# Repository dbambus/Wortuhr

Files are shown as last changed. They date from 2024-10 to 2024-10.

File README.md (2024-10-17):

  
# ESP Wordclock

English description further below.



Dies ist ein Projekt für eine mehrsprachige Wortuhr auf Grundlage eines ESP8266-Mikrocontrollers und einer programmierbaren LED-Leiste (WS2812 oder SK6812). Eine Wortuhr ist ein wunderschönes DIY-Projekt für Anfänger, das Technologie und Design kombiniert, um eine funktionale und ästhetisch ansprechende Uhr zu schaffen. 
Egal, ob Sie ein Anfänger oder ein erfahrener Bastler sind, dieses Projekt ist eine großartige Möglichkeit, Ihre Fähigkeiten unter Beweis zu stellen und etwas wirklich Besonderes zu schaffen.
Die Software hat viele Funktionen:
- Mehrsprachig (🇬🇧, 🇩🇪, 🇪🇸, 🇮🇹, 🇳🇱, 🇭🇺, 🇷🇴, 🇨🇭, 🇷🇺, 🇸🇪, 🇫🇷)
- Unterstützung für mehrere Layouts und LED-Abstände
- Farbwechsel der Displayfarbe möglich (RGB oder RGBW)
- Digitale Uhranzeige
- Regenbogenfarbwechsel
- Umgebungslicht (als Sekundenzeiger ausgeführt) 
- Automatische Helligkeitsregelung (optional über LDR) 
- Auswahl an dialektspezifischen Anzeigen
- Home-Assistant-Einbindung mit Autodiscovery



## Betriebsmodi der Uhr

<p align="center">
Wordclock DigitalClock
Colors Rainbow
Symbol Seconds
ScrollingText Animation
FrameSeconds 
</p>

## Die folgende Hardware/Software wird für dieses Projekt benötigt:
* Hardware
    * NodeMCU oder vergleichbares Board mit einem dem ESP8266 oder ESP8285 Chip
    * WS2812B RGB-LED-Streifen oder SK6812 RGBW-Streifen
    * Stromversorgung 5V 2A
    * Optional: LDR, 10 KOhm-Widerstand

* Software
    * PlatformIO [Core](https://docs.platformio.org/en/latest/core/installation.html) oder [IDE](https://platformio.org/install/ide?install=vscode)
    * [Node.js](https://www.nodejs.org/)
    * [Git](https://git-scm.com)

## Installation 
### Windows

* Installieren Sie PlatformIO IDE, Node.js und Git manuell über die oben genannten Links.
* Dadurch wird Visual Studio Code installiert, mit einem PlatformIO-Symbol (Ameisenkopf/Alien) in der Seitenleiste.
* Gehen Sie zu 'Quick Access / Miscellaneous' und geben Sie den Befehl 'Clone Git Project' ein, und geben Sie 'https://github.com/ESPWortuhr/Wortuhr' als URL ein.
* Gehen Sie dann zu 'Projekte', fügen Sie das neue Projekt mit 'Vorhandenes hinzufügen' zur Liste hinzu und klicken Sie auf 'Öffnen'.
* In der PlatformIO-Seitenleiste erscheint nun 'Project Tasks'. Wählen Sie den Befehl 'General / Upload' (dauert ein paar Minuten, die Software wird zuerst erstellt).
* Schließen Sie den ESP-8266 über USB an. Wenn die Wortuhr-Software erstellt ist, wird sie auf dem ESP installiert.

### MacOS

Der einfachste Weg wäre mit [homebrew](https://docs.brew.sh/Installation):

```sh
brew install platformio
brew install node
git clone https://github.com/ESPWortuhr/Wortuhr
cd Wortuhr
pio run -t upload
```

### Linux

```sh
python3 -c "$(curl -fsSL https://raw.githubusercontent.com/platformio/platformio/master/scripts/get-platformio.py)"
sudo apt install npm
git clone https://github.com/ESPWortuhr/Wortuhr
cd Wortuhr
pio run -t upload
```

## Anschließen des WS2812/ SK6812 LED Streifens
* RX = DI / Datenbus
* G = GND / Masse
* VU = 5V

## Anschluss der Hardware
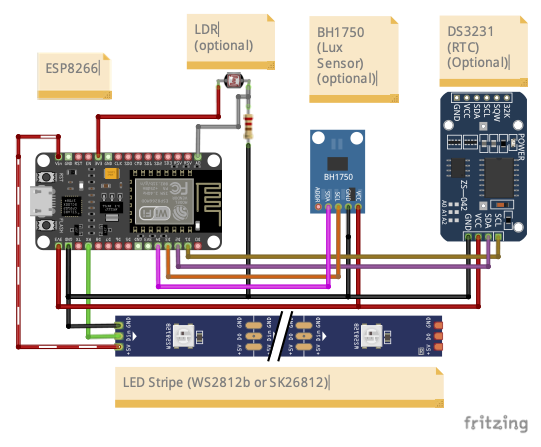
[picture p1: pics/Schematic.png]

      
## Verzeichnisstruktur

- `pics` enthält Bilder
- `svg` enthält SVG-Dateien
- `include` enthält C-Header-Dateien
- `src` enthält C-Quelldateien
- `webpage` enthält das Webinterface
- `docs` enthält Handbücher
- `templates` enthält Fräs- und Laserdaten

### BSD-3 Lizenz

Diese Software ist unter der BSD-Lizenz lizenziert und darf frei verwendet werden. Es ist erlaubt, sie zu kopieren, zu verändern und zu verbreiten.
Die einzige Bedingung ist, dass der Copyright-Hinweis des Originalprogramms nicht entfernt werden darf.

## ENGLISH Textversion



This is a project for a multilingual word clock based on an ESP8266 microcontroller and a programmable LED strip (WS2812 or SK6812). A word clock is a beautiful DIY project for beginners that combines technology and design to create a functional and aesthetically pleasing clock. 
Whether you're a beginner or an experienced hobbyist, this project is a great way to show off your skills and create something truly special.
The software has many features:
- Multilingual  (🇬🇧, 🇩🇪, 🇪🇸, 🇮🇹, 🇳🇱, 🇭🇺, 🇷🇴, 🇨🇭, 🇷🇺, 🇸🇪, 🇫🇷)
- Support for multiple layouts and LED spacing
- Colour change of the display colour possible (RGB or RGBW)
- Digital clock display
- Rainbow colour change
- Ambient light (designed as a second hand) 
- Automatic brightness control (optional via LDR) 
- Selection of dialect-specific displays
- Home Assistant integration with auto-discovery
  


## The following hardware/software are required for this project:
* Hardware
    * NodeMCU (tested board Lolin Version3 and Wemos D3 mini) or comparable board with an ESP8266 
    * WS2812B, WS2816 RGB LED Stripes or SK6812 RGBW Stribes
    * Power supply 5V 2A
    * Optional: LDR, 10 KOhm resistor
* Software
    * PlatformIO [Core](https://docs.platformio.org/en/latest/core/installation.html) or [IDE](https://platformio.org/install/ide?install=vscode)
    * [Node.js](https://www.nodejs.org/)
    * [Git](https://git-scm.com)

## Installation 
### Windows

* Manually install PlatformIO IDE, Node.js and Git using the links above.
* This will install Visual Studio Code, with a PlatformIO icon (ant head/alien) in the sidebar.
* Go to 'Quick Access / Miscellaneous' and enter the command 'Clone Git Project', and enter 'https://github.com/ESPWortuhr/Wortuhr' as the URL.
* Then go to 'Projects', add the new project to the list by 'Add Existing' and click on 'Open'.
* Then in the PlatformIO sidebar 'Project Tasks' appears. Select the command 'General / Upload' (takes a few minutes, the software will be built first).
* Connect the ESP-8266 via USB. When the word clock software is built, it will be installed on the ESP.

### MacOS

The easiest way would be with [homebrew](https://docs.brew.sh/Installation):

```sh
brew install platformio
brew install node
git clone https://github.com/ESPWortuhr/Wortuhr
cd Wortuhr
pio run -t upload
```

### Linux

```sh
python3 -c "$(curl -fsSL https://raw.githubusercontent.com/platformio/platformio/master/scripts/get-platformio.py)"
sudo apt install npm
git clone https://github.com/ESPWortuhr/Wortuhr
cd Wortuhr
pio run -t upload
```

## Connecting the WS2812/ SK6812 Stripe
* RX = DI / Data Bus
* G = GND / Masse
* VU = 5V

## Connection of the hardware

      
## directory structure

- `pics` contains images
- `svg` contains SVG files
- `include` contains C header files
- `src` contains C source files
- `webpage` contains the web interface
- `docs` contains manuals
- `templates` contains milling and laser data

## To DO & (Ideen):
* HomeKit Support
* Home Assistant Support

### BSD-3 License

This software is licensed under the BSD license and may be used freely. It is allowed to copy, modify and distribute it.
The only condition is that the copyright notice of the original program must not be removed.

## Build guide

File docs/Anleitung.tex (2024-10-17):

\documentclass[12pt,a4paper, german,oneside, headinclude, headsepline,plainheadsepline,BCOR20mm, DIV18,parskip=half, openright, numbers=noenddot, captions=tableheading,version=first,listof=totoc,version=first]{scrbook}

\hfuzz=20pt
\vfuzz=20pt

%--------------- Packages ----------------
\usepackage[ngerman]{babel}
\usepackage[utf8]{inputenc}
\usepackage[T1]{fontenc}
\usepackage{lmodern}
\usepackage[centertags]{amsmath} 
\usepackage{tabularx}
\usepackage{graphicx} 
\usepackage{float} 
\usepackage{setspace} 
\usepackage{scrlayer-scrpage}
\usepackage{scrhack}
\usepackage{makeidx}
\usepackage[usenames,dvipsnames,svgnames,table]{xcolor}
\usepackage[absolute]{textpos}
\usepackage{subfigure}
\usepackage{amssymb}
\usepackage{listings}
\usepackage{trfsigns}
\usepackage{siunitx}
\usepackage[abs]{overpic}
\usepackage[colorlinks = false,pdfpagelabels = true,pdfstartview = FitH,bookmarksopen = true,bookmarksnumbered = true,linkcolor = black,plainpages = false,hypertexnames = false,citecolor = black] {hyperref}
\usepackage{pgfplots}
\usepackage[framed,numbered,autolinebreaks,useliterate]{mcode}
\usepackage{xcolor}
\usepackage[
    left = \flqq{},% 
    right = \frqq{},% 
    leftsub = \flq{},% 
    rightsub = \frq{} %
]{dirtytalk}
\lstset{breaklines=true}

\pagestyle{scrheadings}
\renewcommand{\headfont}{\normalfont\sffamily} 
\renewcommand{\pnumfont}{\normalfont\sffamily} 
\ohead[\pagemark]{\pagemark} 
\ifoot[]{}
\ofoot[]{}
\setlength{\headheight}{1.5\baselineskip}
\onehalfspacing

%----------------------- Beginn des Dokuments -----------------------
\begin{document}
\pagenumbering{Roman}
\thispagestyle{empty}
\setcounter{page}{-1}



\vspace{25mm}

{\centering

\LARGE\textbf{{Anleitung}}\\
\vspace{1em}
\large{Für die Multilayout-ESP-Wordclock} \\

\par}

\newpage
\thispagestyle{empty}

\cleardoublepage

\cleardoublestandardpage

\begin{spacing}{1.15}		
\pdfbookmark[1]{Inhaltsverzeichnis}{toc}		
\tableofcontents 		

\end{spacing}

\cleardoublestandardpage

\mainmatter							

\chapter{Einleitung}

Diese Anleitung soll helfen, eine mehrsprachige Wortuhr zu bauen, die auf einem ESP8266 Mikrocontroller und einer programmierbaren LED-Leiste (WS2812 oder SK6812) basiert. Dieses Projekt wurde über mehrere Jahre von einer Vielzahl von Mitwirkenden auf Github entwickelt und frei zur Verfügung gestellt.\\
Eine Wortuhr (auch als Wordclock bekannt) ist ein schönes DIY-Projekt für Anfänger, das Technologie und Design kombiniert, um eine funktionelle und ästhetisch ansprechende Uhr zu schaffen. Egal, ob Sie Anfänger oder erfahrener Bastler sind, dieses Projekt ist eine großartige Gelegenheit, Ihre Fähigkeiten unter Beweis zu stellen und etwas wirklich Besonderes zu schaffen. Die Gestaltungsmöglichkeiten liegen vor allem im Rahmen und in der Wahl der Oberfläche der Uhr. 

\section{Hauptfunktionen}

Die bereitgestellte Software zum Betreiben der Wortuhr hat mehrere Funktionen:

\begin{itemize}
    \item Mehrsprachig (Deutsch, Englisch, Niederländisch, Italienisch, Spanisch, Ungarisch, Französisch, Römänisch, Schweizer Deutsch, Russisch und Schwedisch)
    \item Unterstützung für mehrere Matrizengrößen und LED-Abstände
    \item Farbwechsel der Anzeigefarbe möglich (RGB oder RGBW)
    \item Digitale Uhranzeige
    \item Regenbogenfarbwechsel
    \item Umgebungslicht (als Sekundenzeiger ausgeführt oder Ambientlight)
    \item Automatische Helligkeitsregelung (optional über Sensor)
    \item Offlinebetrieb (optional über entsprechende RTC)
    \item Auswahl an dialektspezifischen Anzeigen
    \item Home-Assistant-Einbindung mit Autodiscovery
\end{itemize}

\section{Uhren Varianten}

\section{Voraussetzungen}

Die folgende Hardware/Software wird für dieses Projekt benötigt:

\subsubsection{Hardware}

\begin{itemize}
    \item NodeMCU oder vergleichbares Board mit einem dem ESP8266 oder ESP8285 Chip
    \item WS2812B RGB-LED-Streifen oder SK6812 RGBW-Streifen
    \item Stromversorgung 5V 2A
    \item Optional: LDR, 10 KOhm-Widerstand
    \item Optional: BH1750 (digitaler Helligkeitssensor, anstallt LDR)
    \item Optional: DS3231 (Echtzeituhr, für den offline Betrieb)
\end{itemize}

\subsubsection{Software}

\begin{itemize}
    \item PlatformIO Core oder IDE (bspw. VIsual Studio Code)
    \item Node.js
    \item Git
\end{itemize}

\chapter{Installation der Wortuhr Software}

\section{Erstmaliges Aufspielen mittels Binary}
Für das erstmalige Aufspielen liegen auf der Githubseite Rechts \say{Releases} zur Verfügung. Dabei handelt es sich um fertig compilierte Versionen der Software. Programme zum aufspielen der binary findet man z.B. unter \say{https://github.com/nodemcu/nodemcu-flasher}

\section{Windows}

\begin{enumerate}
    \item Installieren Sie die aktellsten Versionen von PlatformIO, Node.js und Git manuell
    \item Dadurch wird Visual Studio Code installiert, mit einem PlatformIO-Symbol (Ameisenkopf/Alien) in der Seitenleiste
    \item Gehen Sie zu \say{Quick Access / Miscellaneous} und geben Sie den Befehl \say{Clone Git Project} ein, und geben Sie \href{https://github.com/ESPWortuhr/Multilayout-ESP-Wordclock}{https://github.com/ESPWortuhr/Multilayout-ESP-Wordclock} als URL ein
    \item Gehen Sie dann zu \say{Projekte}, fügen Sie das neue Projekt mit \say{Vorhandenes hinzufügen} zur Liste hinzu und klicken Sie auf \say{Öffnen}.
    \item In der PlatformIO-Seitenleiste erscheint nun \say{Project Tasks}. Wählen Sie den Befehl \say{General / Upload'} (dauert ein paar Minuten, die Software wird zuerst erstellt).
    \item Schließen Sie den ESP8266 über USB an. Wenn die Wortuhr-Software erstellt ist, wird sie auf dem ESP installiert.
\end{enumerate}

\section{MacOS}

Der einfachste Weg wäre mit \say{homebrew}:

\begin{lstlisting}
    brew install platformio
    brew install node
    git clone https://github.com/ESPWortuhr/Wortuhr
    cd Wortuhr
    pio run -t upload
\end{lstlisting}

Dabei ist der ESP8266 über USB angeschlossen. Die Wortuhr-Software wird dabei mittels Plattformio erstellt und auf den ESP übertragen.

\section{Linux}

\begin{lstlisting}
    python3 -c "$(curl -fsSL https://raw.githubusercontent.com/ platformio/platformio/master/scripts/get-platformio.py)"
    sudo apt install npm
    git clone https://github.com/ESPWortuhr/Wortuhr
    cd Wortuhr
    pio run -t upload
\end{lstlisting}

Dabei ist der ESP8266 über USB angeschlossen. Die Wortuhr-Software wird dabei mittels Plattformio erstellt und auf den ESP übertragen.

\section{Update der Firmware über das Web-Frontend}
Mit der Software ist es möglich, die Firmware \textbf{OTA} (over the air), über den in der Uhr eingebauten Webserver zu aktualisieren. Dies ist in den meisten Fällen einfacher als das direkte Flashen.
Ausschlaggebend für diese Vorgehensweise ist, dass die Uhr über WLAN erreichbar ist. Die Update-Schnittstelle ist dann über die Adresse
http://<IP-Adresse der Uhr>:81/update erreichbar (Beispiel: http://192.168.4.1:81/update). Die Adresse der Uhr wird in der Grundeinstellung beim Start als Laufschrift ausgegeben.

\chapter{Hardware}

Für den Aufbau der Wortuhr wird folgende elektronische Hardware benötigt:

\begin{itemize}
    \item NodeMCU oder vergleichbares Board mit ESP8266 oder ESP8285 Chip
    \item RGB-LED-Streifen WS2812B oder RGBW-Streifen SK6812
    \item Stromversorgung 5V 2A
    \item Optional: LDR, 10 KOhm Widerstand
    \item Optional: BH1750 (digitaler Helligkeitssensor, ersetzt LDR)
    \item Optional: DS3231 (Echtzeituhr, für Offline-Betrieb)
\end{itemize}

Ich möchte dich gerne darüber informieren, was du noch alles für den Bau benötigst. Da es verschiedene Arten gibt, eine Uhr zu bauen, werde ich dir hier nur die grundlegenden Dinge aufzählen, die ich oft verwende:

\begin{itemize}
    \item Bilderrahmen (Holz oder Metall mit mindestens 14mm Rahmenhöhe)
    \item Diffusorfolie
    \item Buchstabenmaske
    \item Abstandsgitter (Holz oder Kunststoffschaum)
\end{itemize}

\section{Pegelanpassung}

Der ESP arbeitet intern mit einer Betriebsspannung von 3,3V. Die WS2812(B) Streifen arbeiten dagegen mit 5V. Dies erfordert eine Pegelanpassung, damit die digitalen Signale fehlerfrei zu den Stripes übertragen warden können. Ohne Anpassung kann es auch funktionieren, muss es aber nicht. 
Es gilt: "Der minimale High-Pegel des Ausgangs muss höher sein als der minimale High-Pegel des Eingangs"
Was heißt das im Klartext?
Laut Datenblatt des Stripes sind folgende Pegel notwendig, um ein "sauberes" HIGH und LOW Signal zu bekommen.
Um ein HIGH Signal am Eingang des WS2812B Stripes zu erzeugen, muss laut Datenblatt (Bild 1) mindestens ein Pegel von 4,3V erzeugt werden. Da der ESP aber maximal 3,3V erzeugen kann, wird hier kein sicheres HIGH Signal erzeugt.

Nun kommt der Trick mit der Diode:
Die erste LED wird nun mit einer Diode in der Plus Leitung betrieben. Die Durchlassspannung der Diode beträgt 0,7V. Das heißt, dass die erste Diode mit 4,3V betrieben wird. Das ist laut Datenblatt auch zulässig. Bei 4,3V beträgt der benötigte HIGH Pegel nun noch 3,6V. Da die Hersteller noch Toleranzen mit einberechnen funktioniert das ganze Konstrukt wieder. Nun gibt die erste LED den Pegel mit 4,3V an die nächste LED weiter (diese wird wieder mit 5V betrieben und der HIGH Pegel liegt mit 4,3V wieder im Datenblatt in der Toleranz). Die zweite LED verstärkt sozusagen das Signal wieder auf die volle 5V.
Das heißt, die erste LED wird sozusagen als Pegelanpassung missbraucht.

\section{Anschlussbeispiel}
Der Datenpin des LED Stripes muss zwingend an dem Port \say{Rx} angeschlossen werden. Grund für den festen Pin ist die verwendete Library. Der Pin kann nicht verändert werden (auch nicht in der Config). Wie auf dem muss eine Diode in die +5V Leitung der 1. LED. Die +5V Leitung zwischen der 1. und 2. LED muss durchtrennt werden (aber nur diese, nicht die Daten und GND!).
Am 2. Streifen wird dann zusätzlich vom Netzteil die +5V eingespeist. Die LED´s vom 1. Stripe werden dann sozusagen "rückwärts" mit den nötigen +5V versorgt.

    \begin{figure} [h]
		\centering
		 
		\caption{Anschlussbeispiel}
		\label{abb.Schematic}
	\end{figure}

\chapter{Funktionen der Uhrensoftware auf dem ESP}

\section{Verbinden der Uhr mit dem eigenen WLAN}
Nach dem erfolgreichen Verbinden kann die Uhr nach Eingabe der angezeigten IP-Adresse in einem Browser konfiguriert werden. Dabei kann die Uhr auch mit dem eigenen WLAN Netz verbunden werden.
 
\section{Zeitserver (NTP Server)}
Falls die Uhr an das eigene WLAN mit Internet angebunden wird, kann ein Zeitserver hinterlegt werden. Dieser sorgt dafür, dass die Uhrzeit zyklisch sekundengenau gestellt wird. 
 
\section{Automatische Helligkeitsregelung}
Falls der optionale LDR an der Uhr angeschlossen wurde, ist es möglich, die Helligkeit automatisch, abhängig der Umgebungshelligkeit, regeln zu lassen. Dazu muss folgende Einstellung aktiviert werden. Durch das Feld Kalibrierung kann man die Grundhelligkeit an seine eigenen Wünsche anpassen.

\end{document}

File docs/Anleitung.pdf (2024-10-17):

!!

M | E | S | P | I | W | O | R | D | F
B | A | C | L | O | C | K | D | A | N
E | A | N | A | L | L | E | E | F | T
M | A | N | U | A | L | N | J | L | K

# Anleitung

Für die Multilayout-ESP-Wordclock

# Inhaltsverzeichnis

1 Einleitung | 1
2 Installation der Wortuhr Software | 3
3 Hardware | 5
4 Funktionen der Uhrensoftware auf dem ESP | 8

# 1 Einleitung

Diese Anleitung soll helfen, eine mehrsprachige Wortuhr zu bauen, die auf einem ESP8266 Mikrocontroller und einer programmierbaren LED-Leiste (WS2812 oder SK6812) basiert. Dieses Projekt wurde über mehrere Jahre von einer Vielzahl von Mitwirkenden auf Github entwickelt und frei zur Verfügung gestellt.
Eine Wortuhr (auch als Wordclock bekannt) ist ein schönes DIY-Projekt für Anfänger, das Technologie und Design kombiniert, um eine funktionelle und ästhetisch ansprechende Uhr zu schaffen. Egal, ob Sie Anfänger oder erfahrener Bastler sind, dieses Projekt ist eine großartige Gelegenheit, Ihre Fähigkeiten unter Beweis zu stellen und etwas wirklich Besonderes zu schaffen. Die Gestaltungsmöglichkeiten liegen vor allem im Rahmen und in der Wahl der Oberfläche der Uhr.

## 1.1 Hauptfunktionen

Die bereitgestellte Software zum Betreiben der Wortuhr hat mehrere Funktionen:

- Mehrsprachig (Deutsch, Englisch, Niederländisch, Italienisch, Spanisch, Ungarisch, Französisch, Römänisch, Schweizer Deutsch, Russisch und Schwedisch)
- Unterstützung für mehrere Matrizengrößen und LED-Abstände
- Farbwechsel der Anzeigefarbe möglich (RGB oder RGBW)
- Digitale Uhranzeige
- Regenbogenfarbwechsel
- Umgebungslicht (als Sekundenzeiger ausgeführt oder Ambientlight)
- Automatische Helligkeitsregelung (optional über Sensor)
- Offlinebetrieb (optional über entsprechende RTC)

1 Einleitung | 2
- Auswahl an dialektspezifischen Anzeigen
- Home-Assistant-Einbindung mit Autodiscovery

## 1.2 Uhren Varianten

## 1.3 Voraussetzungen

Die folgende Hardware/Software wird für dieses Projekt benötigt:

Hardware

- NodeMCU oder vergleichbares Board mit einem dem ESP8266 oder ESP8285 Chip
- WS2812B RGB-LED-Streifen oder SK6812 RGBW-Streifen
- Stromversorgung 5V 2A
- Optional: LDR, 10 KOhm-Widerstand
- Optional: BH1750 (digitaler Helligkeitssensor, anstallt LDR)
- Optional: DS3231 (Echtzeituhr, für den offline Betrieb)

Software

- PlatformIO Core oder IDE (bspw. VIsual Studio Code)
- Node.js
- Git

# 2 Installation der Wortuhr Software

## 2.1 Erstmaliges Aufspielen mittels Binary

Für das erstmalige Aufspielen liegen auf der Githubseite Rechts «Releases» zur Verfügung. Dabei handelt es sich um fertig compilierte Versionen der Software. Programme zum aufspielen der binary findet man z.B. unter «https://github.com/nodemcu/nodemcuflasher»

## 2.2 Windows

1. Installieren Sie die aktellsten Versionen von PlatformIO, Node.js und Git manuell
2. Dadurch wird Visual Studio Code installiert, mit einem PlatformIO-Symbol (Ameisenkopf/Alien) in der Seitenleiste
3. Gehen Sie zu «Quick Access / Miscellaneous» und geben Sie den Befehl «Clone Git Project» ein, und geben Sie https://github.com/ESPWortuhr/Multilayout-ESP-Wordclock als URL ein
4. Gehen Sie dann zu «Projekte», fügen Sie das neue Projekt mit «Vorhandenes hinzufügen» zur Liste hinzu und klicken Sie auf «Öffnen».
5. In der PlatformIO-Seitenleiste erscheint nun «Project Tasks». Wählen Sie den Befehl «General / Upload’» (dauert ein paar Minuten, die Software wird zuerst erstellt).
6. Schließen Sie den ESP8266 über USB an. Wenn die Wortuhr-Software erstellt ist, wird sie auf dem ESP installiert.

2 Installation der Wortuhr Software | 4

## 2.3 MacOS

Der einfachste Weg wäre mit «homebrew»:

1 | brew install platformio
2 | brew install node
3 | git clone https://github.com/ESPWortuhr/Wortuhr
4 | cd Wortuhr
5 | pio run -t upload

Dabei ist der ESP8266 über USB angeschlossen. Die Wortuhr-Software wird dabei mittels Plattformio erstellt und auf den ESP übertragen.

## 2.4 Linux

1 | python3 -c "$(curl -fsSL https://raw.githubusercontent.com/ ...
| platformio/platformio/master/scripts/get-platformio.py)"
2 | sudo apt install npm
3 | git clone https://github.com/ESPWortuhr/Wortuhr
4 | cd Wortuhr
5 | pio run -t upload

Dabei ist der ESP8266 über USB angeschlossen. Die Wortuhr-Software wird dabei mittels Plattformio erstellt und auf den ESP übertragen.

## 2.5 Update der Firmware über das Web-Frontend

Mit der Software ist es möglich, die Firmware OTA (over the air), über den in der Uhr eingebauten Webserver zu aktualisieren. Dies ist in den meisten Fällen einfacher als das direkte Flashen. Ausschlaggebend für diese Vorgehensweise ist, dass die Uhr über WLAN erreichbar ist. Die Update-Schnittstelle ist dann über die Adresse http://<IP-Adresse der Uhr>:81/update erreichbar (Beispiel: http://192.168.4.1:81/update). Die Adresse der Uhr wird in der Grundeinstellung beim Start als Laufschrift ausgegeben.

# 3 Hardware

Für den Aufbau der Wortuhr wird folgende elektronische Hardware benötigt:

- NodeMCU oder vergleichbares Board mit ESP8266 oder ESP8285 Chip
- RGB-LED-Streifen WS2812B oder RGBW-Streifen SK6812
- Stromversorgung 5V 2A
- Optional: LDR, 10 KOhm Widerstand
- Optional: BH1750 (digitaler Helligkeitssensor, ersetzt LDR)
- Optional: DS3231 (Echtzeituhr, für Offline-Betrieb)

Ich möchte dich gerne darüber informieren, was du noch alles für den Bau benötigst. Da es verschiedene Arten gibt, eine Uhr zu bauen, werde ich dir hier nur die grundlegenden Dinge aufzählen, die ich oft verwende:

- Bilderrahmen (Holz oder Metall mit mindestens 14mm Rahmenhöhe)
- Diffusorfolie
- Buchstabenmaske
- Abstandsgitter (Holz oder Kunststoffschaum)

3 Hardware | 6

## 3.1 Pegelanpassung

Der ESP arbeitet intern mit einer Betriebsspannung von 3,3V. Die WS2812(B) Streifen arbeiten dagegen mit 5V. Dies erfordert eine Pegelanpassung, damit die digitalen Signale fehlerfrei zu den Stripes übertragen warden können. Ohne Anpassung kann es auch funktionieren, muss es aber nicht. Es gilt: "Der minimale High-Pegel des Ausgangs muss höher sein als der minimale High-Pegel des Eingangs"Was heißt das im Klartext? Laut Datenblatt des Stripes sind folgende Pegel notwendig, um ein ßauberes"HIGH und LOW Signal zu bekommen. Um ein HIGH Signal am Eingang des WS2812B Stripes zu erzeugen, muss laut Datenblatt (Bild 1) mindestens ein Pegel von 4,3V erzeugt werden. Da der ESP aber maximal 3,3V erzeugen kann, wird hier kein sicheres HIGH Signal erzeugt.
Nun kommt der Trick mit der Diode: Die erste LED wird nun mit einer Diode in der Plus Leitung betrieben. Die Durchlassspannung der Diode beträgt 0,7V. Das heißt, dass die erste Diode mit 4,3V betrieben wird. Das ist laut Datenblatt auch zulässig. Bei 4,3V beträgt der benötigte HIGH Pegel nun noch 3,6V. Da die Hersteller noch Toleranzen mit einberechnen funktioniert das ganze Konstrukt wieder. Nun gibt die erste LED den Pegel mit 4,3V an die nächste LED weiter (diese wird wieder mit 5V betrieben und der HIGH Pegel liegt mit 4,3V wieder im Datenblatt in der Toleranz). Die zweite LED verstärkt sozusagen das Signal wieder auf die volle 5V. Das heißt, die erste LED wird sozusagen als Pegelanpassung missbraucht.

## 3.2 Anschlussbeispiel

Der Datenpin des LED Stripes muss zwingend an dem Port «Rx» angeschlossen werden. Grund für den festen Pin ist die verwendete Library. Der Pin kann nicht verändert werden (auch nicht in der Config). Wie auf dem muss eine Diode in die +5V Leitung der 1. LED. Die +5V Leitung zwischen der 1. und 2. LED muss durchtrennt werden (aber nur diese, nicht die Daten und GND!). Am 2. Streifen wird dann zusätzlich vom Netzteil die +5V eingespeist. Die LEDs vom 1. Stripe werden dann sozusagen "rückwärts"mit den nötigen +5V versorgt.

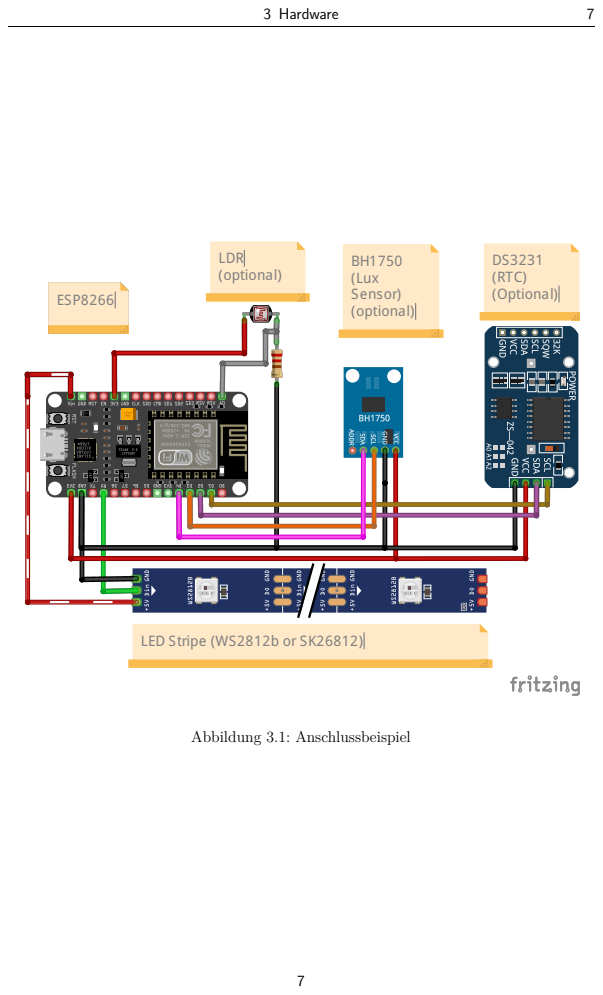
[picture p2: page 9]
3 Hardware; DS3231 (RTC) (Optional); BH1750 (Lux Sensor) (optional); ESP8266; LDR (optional); Abbildung 3.1: Anschlussbeispiel

LED Stripe (WS2812b or SK26812)

# 4 Funktionen der Uhrensoftware auf dem ESP

## 4.1 Verbinden der Uhr mit dem eigenen WLAN

Nach dem erfolgreichen Verbinden kann die Uhr nach Eingabe der angezeigten IP-Adresse in einem Browser konfiguriert werden. Dabei kann die Uhr auch mit dem eigenen WLAN Netz verbunden werden.

## 4.2 Zeitserver (NTP Server)

Falls die Uhr an das eigene WLAN mit Internet angebunden wird, kann ein Zeitserver hinterlegt werden. Dieser sorgt dafür, dass die Uhrzeit zyklisch sekundengenau gestellt wird.

## 4.3 Automatische Helligkeitsregelung

Falls der optionale LDR an der Uhr angeschlossen wurde, ist es möglich, die Helligkeit automatisch, abhängig der Umgebungshelligkeit, regeln zu lassen. Dazu muss folgende Einstellung aktiviert werden. Durch das Feld Kalibrierung kann man die Grundhelligkeit an seine eigenen Wünsche anpassen.

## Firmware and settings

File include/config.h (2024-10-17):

/*
 * This is the default word clock configuration. You can also change it later
 * in the settings menu on the clock's hosted website.
 */

//--------------------------------------------------------------------------
// Front panel layout
//--------------------------------------------------------------------------
/**********************/
/*       German       */
/**********************/
//
#define DEFAULT_LAYOUT Ger10x11
// 10 rows, 11 LEDs per row + 4 LEDs for minutes
//
// #define DEFAULT_LAYOUT Ger10x11Alternative
// 10 rows, each 11 LED's per row + 4 LED's for minutes, with modified
// layout for extra words in the matrix from the Github user @dbambus
//
// #define DEFAULT_LAYOUT Ger10x11AlternativeFrame
// 10 rows, each 11 LED's per row + 4 LED's (minutes)+ 48 LED's (seconds) in a
// Frame around with modified layout for extra words in the matrix from the
// Github user @dbambus
//
// #define DEFAULT_LAYOUT Ger10x11Clock
// 10 rows, each 11 LED's per row + 4 LED's for minutes, with the layout
// from the original manufacturer
//
// #define DEFAULT_LAYOUT Ger10x11schwaebisch
// 10 rows, each 11 LED's per row + 4 LED's for minutes, with the layout
// from the original manufacturer
//
// #define DEFAULT_LAYOUT Ger10x11Nero
// 10 rows, each 11 LED's per row + 4 LED's for minutes, with the layout
// from the Github user @n3roGit
//
// #define DEFAULT_LAYOUT Ger11x11
// 11 rows, each 11 LED's per row + 4 LED's for minutes
//
// #define DEFAULT_LAYOUT Ger11x11V2
// 11 rows, each 11 LED's per row + 4 LED's for minutes plus twenty word
//
// #define DEFAULT_LAYOUT Ger11x11V3
// 11 rows, each 11 LED's per row. Layout for panbachi/wordclock plate design
//
// #define DEFAULT_LAYOUT Ger11x11Frame
// Same Layout as Ger11x11, but with additional LED's to illuminate the frame
// from the side
//
// #define DEFAULT_LAYOUT Ger22x11Weather
// 22 rows, each 11 LED's per row, with weather forecast on overall 242 LED's
// based on design of Github user @Eisbaeeer
//
// #define DEFAULT_LAYOUT Ger16x8
// 16 rows, each 8 LED's per row, based on a 16x16 presoldered WS2812b matrix
// and a 3D printed case
//
// #define DEFAULT_LAYOUT Ger16x18
// 16 rows, each 18 LED's per row, with the layout WordClock24h of
// mikrocontroller.net
//
//
/**********************/
/*       Dutch        */
/**********************/
//
// #define DEFAULT_LAYOUT  Nl10x11
// 10 rows, each 11 LED's per row + 4 LED's for minutes, with changed
// layout for Dutch language
//
/**********************/
/*       English      */
/**********************/
//
// #define DEFAULT_LAYOUT  Eng10x11
// 10 rows, 11 LED's per row + 4 LED's for minutes, with modified
// layout for the English language

/**********************/
/*       Italian      */
/**********************/
//
// #define DEFAULT_LAYOUT  It10x11
// 10 rows, 11 LED's per row + 4 LED's for minutes, with modified
// layout for the Italian language

/**********************/
/*       Spanish      */
/**********************/
//
// #define DEFAULT_LAYOUT  Es10x11
// 10 rows, 11 LED's per row + 4 LED's for minutes, with modified
// layout for the Spanish language

/**********************/
/*      Hungarian     */
/**********************/
//
// #define DEFAULT_LAYOUT  Hu10x10
// 10 rows, 10 LED's per row + 4 LED's for minutes, with modified
// layout for the Hungarian language

/**********************/
/*    Swiss German    */
/**********************/
//
// #define DEFAULT_LAYOUT  Ch10x11
// 10 rows, 11 LED's per row + 4 LED's for minutes, with modified
// layout for the Swiss German language

/**********************/
/*      Romanian      */
/**********************/
//
// #define DEFAULT_LAYOUT  Ro10x11
// 10 rows, 11 LED's per row + 4 LED's for minutes, with modified
// layout for the Romanian language

/**********************/
/*       French       */
/**********************/
//
// #define DEFAULT_LAYOUT  Fr10x11
// 10 rows, 11 LED's per row + 4 LED's for minutes, with modified
// layout for the French language

/**********************/
/*       Russian      */
/**********************/
//
// #define DEFAULT_LAYOUT  Ru10x11
// 10 rows, 11 LED's per row + 4 LED's for minutes, with modified
// layout for the Russian language

/**********************/
/*       Swedish      */
/**********************/
//
// #define DEFAULT_LAYOUT  Se10x11
// 10 rows, 11 LED's per row + 4 LED's for minutes, with modified
// layout for the Swedish language

//--------------------------------------------------------------------------
// Define LED Type
//--------------------------------------------------------------------------
/*
 * So far, WS2812 or SK6812 LED strips are supported. Different manufacturers of
 * these strips use different colour layouts, so you can adjust it accordingly
 * with DEFAULT_LEDTYPE. If you have an RGBW LED strip, you can also use
 * WHITE_LEDTYPE to specify the type of white LED used (WarmWhite (3000K),
 * NeutralWhite (4300K) or ColdWhite (6500K)), in the case of RGB just leave it
 * at NeutralWhite.
 *
 * Valid values for DEFAULT_LEDTYPE [Brg, Grb, Rgb, Rbg, Grbw]
 *
 * Valid values for WHITE_LEDTYPE [WarmWhite, NeutralWhite, ColdWhite]
 */
#define DEFAULT_LEDTYPE Brg
#define WHITE_LEDTYPE WhiteType::NeutralWhite

//--------------------------------------------------------------------------
// Define Build Type
//--------------------------------------------------------------------------
/*
 * There are several ways to build wordclocks:
 *
 * For small and mediumsized wordclocks, each LED is used in a strip, such as.
 *
 * [x x x x x x x x] = (Normal)
 *
 * Some variants of wordclocks (mostly midsized - 40x40 cm) rely on Ledstripes
 * with 74LEDs/m with one LED skipped for the Frontmatrix. It is build with 21
 * LEDs per line, for example:
 *
 * [x - x - x - x - x - x - x - x - x] = (DoubleResM1)
 *
 *
 * Valid values:
 * [BuildTypeDef::Normal, BuildTypeDef::DoubleResM1]
 */
#define DEFAULT_BUILDTYPE BuildTypeDef::Normal

//--------------------------------------------------------------------------
// Define External Realtime Clock
//--------------------------------------------------------------------------
/*
 * If you want to use an external RTC it must be defined here, for examle for
 * Wifi less Operation of the clock.
 * However, one must always be defined, even if none is installed.
 *
 * Valid values [RTC_DS1307, RTC_PCF8523, RTC_DS3231]
 */
#define RTC_Type RTC_DS3231

//--------------------------------------------------------------------------
// Serial Number
//--------------------------------------------------------------------------
/*
 * To delete or initialize the EEPROM, enter another serial number here.
 *
 * Valid values [0 ... 255]
 */
#define SERNR 58
//--------------------------------------------------------------------------
// Toggle Serial DEBUG Output
//--------------------------------------------------------------------------
/*
 * To delete or initialize the EEPROM, enter another serial number here.
 *
 * Valid values [true, false]
 */
#define GENERAL_VERBOSE true
#define WEATHER_VERBOSE false

//--------------------------------------------------------------------------
// Manual Wifi settings
//--------------------------------------------------------------------------
/*
 * Here you can set the WiFi connection settings manually. The clock can be
 * paired with a new WiFi, but the setting made here is set again when the
 * clock is restarted.
 *
 * Valid values MANUAL_WIFI_SETTINGS [true, false]
 * Valid values WIFI_SSID [up to 64 Alphanumeric Letters]
 * Valid values WIFI_PASSWORD [up to 64 Alphanumeric Letters]
 *
 */
#define MANUAL_WIFI_SETTINGS false
#define WIFI_SSID "WIFISSID"
#define WIFI_PASSWORD "Password"

//--------------------------------------------------------------------------
// Settings for Boot sequence
//--------------------------------------------------------------------------
/*
 * Show Ip Adress of clock on boot, with BOOT_SHOWIP
 * Light up LEDs on boot, with BOOT_LEDSWEEP
 *
 * Valid values BOOT_SHOWIP [true, false]
 * Valid values BOOT_LEDSWEEP [true, false]
 */
#define BOOT_SHOWIP true
#define BOOT_LEDSWEEP false

//--------------------------------------------------------------------------
// Displaying Option for Minutes
//--------------------------------------------------------------------------
/*
 * Valid values [only one #define option]
 */
// #define MINUTE_Off
#define MINUTE_LED4x
// #define MINUTE_LED7x

//--------------------------------------------------------------------------
// Front Displaying Options
//--------------------------------------------------------------------------
/*
 * Valid values REVERSE_MINUTE_DIR [true, false]
 * Valid values MIRROR_FRONT_VERTICAL [true, false]
 * Valid values MIRROR_FRONT_HORIZONTAL [true, false]
 */
#define REVERSE_MINUTE_DIR false
#define MIRROR_FRONT_VERTICAL false
#define MIRROR_FRONT_HORIZONTAL false

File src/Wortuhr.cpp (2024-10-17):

#include <Arduino.h>
#include <ArduinoJson.h>
#ifdef ESP8266
#include <ESP8266HTTPUpdateServer.h>
#include <ESP8266WebServer.h>
#include <ESP8266WiFi.h>
#include <ESP8266mDNS.h>
#include <coredecls.h>
#elif defined(ESP32)
#include <ESPmDNS.h>
#include <HTTPUpdateServer.h>
#include <Update.h>
#include <WebServer.h>
#include <WiFi.h>
#endif
#include <NeoPixelBus.h>
#include <RTClib.h>
#include <WiFiClient.h>
#include <WiFiUdp.h>
#include <Wire.h>
#include <sntp.h>

#include "Uhr.h"

#include "EEPROMAnything.h"
#include "config.h"
#include "uhrtype.gen.h"
#include "webPageAdapter.h"

iUhrType *usedUhrType = nullptr;

#include "NeoMultiFeature.hpp"

#ifdef ESP8266
NeoPixelBus<NeoMultiFeature, Neo800KbpsMethod> *strip_RGB = NULL;
NeoPixelBus<NeoGrbwFeature, Neo800KbpsMethod> *strip_RGBW = NULL;
#elif defined(ESP32)
NeoPixelBus<NeoGrbwFeature, NeoEsp32I2s1X8Sk6812Method> *strip_RGBW = NULL;
NeoPixelBus<NeoMultiFeature, NeoEsp32I2s1X8Ws2812xMethod> *strip_RGB = NULL;
#endif

WiFiClient client;

//--OTA--
#ifdef ESP8266
ESP8266WebServer httpServer(81);
ESP8266HTTPUpdateServer httpUpdater;
#elif defined(ESP32)
WebServer httpServer(81);
HTTPUpdateServer httpUpdater;
#endif
//--OTA--

// Timezone from
// https://github.com/nayarsystems/posix_tz_db/blob/master/zones.csv
const char TZ_Europe_Berlin[] = "CET-1CEST,M3.5.0,M10.5.0/3";

RTC_Type RTC;

#include "Transitiontypes/Transition.h"
#include "clockWork.h"
#include "frame.h"
#include "led.h"
#include "mqtt.h"
#include "network.h"

Transition *transition;
SecondsFrame *secondsFrame;
Led led;
ClockWork clockWork;
Mqtt mqtt;
Network network;

#include "Transitiontypes/Transition.hpp"
#include "Wifi.hpp"
#include "clockWork.hpp"
#include "icons.h"
#include "led.hpp"
#include "mqtt.hpp"
#include "network.hpp"

#define EEPROM_SIZE 512
_Static_assert(sizeof(G) <= EEPROM_SIZE,
               "Datenstruktur G zu gross für reservierten EEPROM Bereich");

uint16_t powerCycleCountAddr =
    EEPROM_SIZE - 1;          // Address in EEPROM to store power cycle count
uint16_t powerCycleCount = 0; // Variable to store power cycle count

//------------------------------------------------------------------------------

uint32_t sntp_startup_delay_MS_rfc_not_less_than_60000() {
    if (externalRTC) {
        Serial.println("SNTP startup delay 1min");
        return 60000;
    } else {
        // yes this is against the RFC, but we don't have an RTC and want the
        // time now.
        Serial.println("no RTC clock - disable SNTP startup delay");
        return 500;
    }
}

//------------------------------------------------------------------------------

void time_is_set() {
    time_t utc = time(nullptr);
    if (externalRTC) {
        RTC.adjust(DateTime(utc));
    }

    struct tm tm;
    localtime_r(&utc, &tm);
    _second = tm.tm_sec;
    _minute = tm.tm_min;
    _hour = tm.tm_hour;
    if (usedUhrType->numPixelsFrameMatrix() != 0) {
        _secondFrame = _second / (usedUhrType->numPixelsFrameMatrix() / 60.f);
    }

    String origin;
    if (sntp_getreachability(0)) {
        origin = sntp_getservername(0);
        if (origin.length() == 0) {
            const ip_addr_t *ip_addr = sntp_getserver(0);
#ifdef ESP8266
            origin = IPAddress(ip_addr->addr).toString();
#elif defined(ESP32)
            origin = IPAddress(ip_addr->u_addr.ip4.addr).toString();
#endif
        }
    } else {
        origin = "SNTP not reachable";
    }
    Serial.printf("Set new time: %02d:%02d:%02d (%s)\n", _hour, _minute,
                  _second, origin.c_str());

    G.progInit = true;
    parametersChanged = true;
}

//------------------------------------------------------------------------------

void incrementPowerCycleCount() {
    if (powerCycleCount > 5) {
        powerCycleCount = 0;
    }
    powerCycleCount++;
    EEPROM.write(powerCycleCountAddr, powerCycleCount);
    EEPROM.commit();
}

//------------------------------------------------------------------------------
// Start setup()
//------------------------------------------------------------------------------

void setup() {
    //-------------------------------------
    // Start serial interface if required
    //-------------------------------------
#if GENERAL_VERBOSE
    Serial.begin(460800);
    Serial.println("");
    Serial.println("--------------------------------------");
    Serial.println("Begin Setup");
    Serial.println("--------------------------------------");
#endif
    //-------------------------------------
    // Read / initialize EEPROM
    //-------------------------------------

    EEPROM.begin(EEPROM_SIZE);
    eeprom::read();

    //-------------------------------------

    // Read the power cycle count from EEPROM
    powerCycleCount = EEPROM.read(powerCycleCountAddr);
    incrementPowerCycleCount();
    Serial.print("Power cycle count: ");
    Serial.println(powerCycleCount);
    if (powerCycleCount == 5) {
        G.sernr++;
        Serial.println("Reset to initial values");
    }

    //-------------------------------------

    if (G.sernr != SERNR) {
        for (uint16_t i = 0; i < EEPROM_SIZE; i++) {
            EEPROM.write(i, i);
        }
        EEPROM.commit();

        G.sernr = SERNR;
        G.prog = 1;
        G.param1 = 0;
        G.progInit = true;
        G.conf = COMMAND_IDLE;
        for (uint8_t i = 0; i < 3; i++) {
            G.color[i] = {0, 0, 0};
        }
        G.color[Foreground] = HsbColor(120 / 360.f, 1.f, 0.5f);
        G.effectBri = 2;
        G.effectSpeed = 10;
        G.client_nr = 0;
        G.secondVariant = SecondVariant::Off;
// C++23 #elifdef doesn't work yet
#ifdef MINUTE_Off
        G.minuteVariant = MinuteVariant::Off;
#endif
#ifdef MINUTE_LED4x
        G.minuteVariant = MinuteVariant::LED4x;
#endif
#ifdef MINUTE_LED7x
        G.minuteVariant = MinuteVariant::LED7x;
#endif
        strcpy(G.openWeatherMap.cityid, "");
        strcpy(G.openWeatherMap.apikey, "");
        strcpy(G.timeserver, "europe.pool.ntp.org");
        strcpy(G.hostname, "ESPWordclock");
        strcpy(G.scrollingText, "HELLO WORLD ");

        G.h6 = 100;
        G.h8 = 100;
        G.h12 = 100;
        G.h16 = 100;
        G.h18 = 100;
        G.h20 = 100;
        G.h22 = 100;
        G.h24 = 100;
        G.layoutVariant[ReverseMinDirection] = REVERSE_MINUTE_DIR;
        G.layoutVariant[MirrorVertical] = MIRROR_FRONT_VERTICAL;
        G.layoutVariant[MirrorHorizontal] = MIRROR_FRONT_HORIZONTAL;
        for (uint8_t i = 0;
             i < sizeof(G.languageVariant) / sizeof(G.languageVariant[0]);
             i++) {
            G.languageVariant[i] = false;
        }
        G.mqtt.state = false;
        G.mqtt.port = 1883;
        strcpy(G.mqtt.serverAdress, "192.168.4.1");
        strcpy(G.mqtt.user, "User");
        strcpy(G.mqtt.password, "Password");
        strcpy(G.mqtt.clientId, "ClientId");
        strcpy(G.mqtt.topic, "ESPWordclock");

        G.UhrtypeDef = DEFAULT_LAYOUT;
        G.buildTypeDef = DEFAULT_BUILDTYPE;
        G.Colortype = DEFAULT_LEDTYPE;
        G.wType = WHITE_LEDTYPE;

        G.bootLedBlink = false;
        G.bootLedSweep = BOOT_LEDSWEEP;
        G.bootShowWifi = true;
        G.bootShowIP = BOOT_SHOWIP;

        G.autoBrightEnabled = 0;
        G.autoBrightOffset = 100;
        G.autoBrightSlope = 10;
        G.transitionType = 0; // Transition::NO_TRANSITION;
        G.transitionDuration = 2;
        G.transitionSpeed = 30;
        G.transitionColorize = 0;
        G.transitionDemo = false;

        for (uint8_t i = 0; i < MAX_BIRTHDAY_COUNT; i++) {
            G.birthday[i].day = 1;
            G.birthday[i].month = 1;
            G.birthday[i].year = 1900;
        }

        eeprom::write();
        Serial.println("eeprom schreiben");
    }

    // Initialization of COMMAND_MODE_xxx (color)
    G.progInit = true;

    //-------------------------------------
    // Get Pointer for Uhrtype
    //-------------------------------------

    usedUhrType = clockWork.getPointer(G.UhrtypeDef);

    // Area that will be animated:
    //         LED frame horizontal
    //         LED frame vertical
    //         Number of rows (including frames)
    //         Number of columns (including frames)
    // Get TODO frame width from usedUhrTyp
    transition = new Transition(usedUhrType->rowsWordMatrix(),
                                usedUhrType->colsWordMatrix());

    if (usedUhrType->numPixelsFrameMatrix() != 0) {
        secondsFrame = new SecondsFrame(usedUhrType->numPixelsFrameMatrix());
    } else {
        secondsFrame = nullptr;
    }

    //-------------------------------------
    // Initialize LEDs
    //-------------------------------------

    Serial.println("LED Init");
    clockWork.initLedStrip(G.Colortype);
    if (G.bootLedBlink) {
        clockWork.initBootLedBlink();
        delay(20);
    }
    if (G.bootLedSweep) {
        clockWork.initBootLedSweep(20);
    }
    clockWork.initBootLed();

    G.conf = COMMAND_IDLE;

    //-------------------------------------
    // Start external real-time clock
    //-------------------------------------

    if (RTC.begin() == true) {
        Serial.println("External real-time clock found");
        struct timeval tv;
        tv.tv_sec = RTC.now().unixtime();
        settimeofday(&tv, nullptr);
        network.rtcMode();
        externalRTC = true;
    } else {
        Serial.println("No external real-time clock found");
        externalRTC = false;
    }
#ifdef ESP8266
    settimeofday_cb(time_is_set);
#endif

    //-------------------------------------
    // Start WiFi
    //-------------------------------------

    if (G.bootShowWifi) {
        led.setIcon(WLAN100);
    }
    network.setup(G.hostname);
    int strength = network.getQuality();
    Serial.printf("Signal strength: %i\n", strength);
    wifiStart();
    configTime(0, 0, G.timeserver);
    setenv("TZ", TZ_Europe_Berlin, true);
    tzset();

    delay(50);

    //-------------------------------------
    // OTA
    //-------------------------------------

    httpUpdater.setup(&httpServer);
    httpServer.onNotFound([]() {
        // redirect port 81 not found pages to port 80
        httpServer.sendHeader(
            "Location", "http://" + WiFi.localIP().toString() + "/", true);
        httpServer.send(308, "text/plain", "");
    });
    httpServer.begin();

    //-------------------------------------
    // MQTT
    //-------------------------------------

    if (G.mqtt.state) {
        mqtt.init();
    }

    //-------------------------------------
    // Start Websocket
    //-------------------------------------

    webSocket.begin();
    webSocket.onEvent(webSocketEvent);

    Serial.println("Websocket started");

    //-------------------------------------
    // mDNS
    //-------------------------------------
    MDNS.begin(G.hostname);
    MDNS.addService("http", "tcp", 80);
    MDNS.addService("http", "tcp", 81);

    //-------------------------------------
    Serial.println("--------------------------------------");
    Serial.println("ESP Uhr");
    Serial.printf("Version         : %s\n", VERSION);

#ifdef ESP8266
    Serial.printf("Chip ID         : %08X\n", ESP.getChipId());
    Serial.printf("CPU Speed       : %u MHz \n\n", ESP.getCpuFreqMHz());
#elif defined(ESP32)
    Serial.printf("Chip ID         : %08X\n", (uint32_t)ESP.getEfuseMac());
    Serial.printf("CPU Speed       : %u MHz \n\n", getCpuFrequencyMhz());
#endif

    Serial.printf("Flash Size : %u KByte\n", ESP.getFlashChipSize() / 1024);
    Serial.printf("Flash ide Speed : %u\n\n", ESP.getFlashChipSpeed());

    Serial.printf("Free Heap Size  : %u Byte\n", ESP.getFreeHeap());
    Serial.printf("Sketch Size     : %u Byte \n", ESP.getSketchSize());
    Serial.printf("Free Sketch Size: %u Byte \n\n", ESP.getFreeSketchSpace());

    Serial.printf("SDK Version     : %s\n", ESP.getSdkVersion());
    Serial.print("COMPILED        : ");
    Serial.print(__DATE__);
    Serial.print(" ");
    Serial.println(__TIME__);

    Serial.println("--------------------------------------");
    Serial.println("Ende Setup");
    Serial.println("--------------------------------------");
    Serial.println("");

    //-------------------------------------
    // Reset Powercycle Counter
    //-------------------------------------
    delay(500);
    powerCycleCount = 0;
    EEPROM.write(powerCycleCountAddr, powerCycleCount);
    EEPROM.commit();

    //-------------------------------------
    // Transition Init
    //-------------------------------------
    transition->init();

    //-------------------------------------
    // Setup Done
    //-------------------------------------
    parametersChanged = true;
}

//------------------------------------------------------------------------------
// Start loop()
//------------------------------------------------------------------------------

void loop() {
    time_t utc = time(nullptr);
    struct tm tm;
    localtime_r(&utc, &tm);
    if (utc > 100000000) {
        _second = tm.tm_sec;
        _minute = tm.tm_min;
        _hour = tm.tm_hour;
    }

    network.loop();

#ifdef ESP8266
    MDNS.update();
#endif

    httpServer.handleClient();

    webSocket.loop();

    //------------------------------------------------
    // MQTT
    //------------------------------------------------
    if (G.mqtt.state && WiFi.status() == WL_CONNECTED) {
        mqtt.loop();
    }

    transition->loop(tm); // must be called periodically

    // make the time run faster in the demo mode of the transition
    transition->demoMode(_minute, _second);

    if (usedUhrType->numPixelsFrameMatrix() != 0) {
        secondsFrame->loop();
    }

    clockWork.loop(tm);
}

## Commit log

2025-12-02 Added Fritzing Schematic
    [Word.fzz]
2025-12-02 Updated ESP32C3 Partition mapping
    [partitions_singleapp_large.csv]
